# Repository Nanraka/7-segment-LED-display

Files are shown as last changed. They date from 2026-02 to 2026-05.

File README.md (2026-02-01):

# 7 segment LED display

hi

## What is it?
Seven-segment LEDs are commonly used to display numbers, but by combining multiple units, it is also possible to display images and arbitrary patterns.  
I built a system that controls a large number of seven-segment LEDs to display image data and custom-designed patterns as a large-scale display.

For more details, see: > https://elchika.com/article/256d17d7-ee96-4fee-8e8a-b19cc3068b17/

---
## HW
final

SPRESENSE was used for control.  
The seven-segment LEDs were controlled using a shift register with a dynamic (multiplexed) driving method.

The PCB design data is available here: > https://github.com/Nanraka/7-segment-LED-display/tree/main/schematics

Please refer to the table below for the connections to the display.  
To distribute the signal lines, I built a custom Arduino shield mounted on the SPRESENSE.

| Spresense Extension Board Pin | Display Pin | Description |
|---|---|---|
| D13 (SCK) | SCLK | SPI clock signal |
| D11 (MOSI) | SER, TSER | Data input (branched to SER and TSER) |
| D9 (CS) | CS | Chip select (Anode-side shift register) |
| D9 | RESET | Shift register output enable |
| D3 | TRCLK | Chip select (Cathode-side shift register) |
| D1 | OE | Shift register output enable |
| GND | GND | Ground (common reference) |

⚠️ Please connect a dedicated power supply to the VCC terminal of the seven-segment display.  
⚠️ Do not connect it to the SPRESENSE Vout 5V pin.

---
## SW

sw

The data sent from SPRESENSE to the display is prepared in advance on a PC.  
Python is used to convert the image data to be displayed into binary data.

The software data is available here: > https://github.com/Nanraka/7-segment-LED-display/tree/main/src

### 1. `make_base_csv.py`
This script generates mask data.

### 2. `img_2_serial.py`
This script performs the following processes:

- Resizes the input image  
- Converts the image to a binary (black-and-white) format, reads it column by column, converts it into serial data, and saves the result as `.txt` and `.csv` files  
- Rearranges the serial data into an order that can be visually recognized as an image by humans, and saves it as a `.csv` file

### 3. `make_data_for_7seg.py`
This script performs the following processes:

- Loads mask data that defines the positions of the seven-segment digits  
- Combines the image serial data with the mask data to generate data for displaying on the seven-segment LEDs

### 4. `7seg_spresense.ino`
- This program sends data to the seven-segment display in LSB-first order.
- The `.txt` file generated by `make_data_for_7seg.py` is stored on a microSD card and read by the SPRESENSE for use.

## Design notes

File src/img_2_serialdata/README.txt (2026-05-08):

SWを動かす順番

0. make_base_csv.py
    ・7セグのデジットの場所を示したマスクデータを生成します．

1. img_2_serial.py
    ・入力画像をリサイズします．
    ・画像を2値化して列方向に読み取りシリアル変換し，txtファイル，csvファイルに保存します．
    ・シリアルデータを人が画像として認識できる順番に変換してCSVファイルに保存します．
    ・出力用CSVファイル：serial_data_csv
    ・出力用TXTファイル：serial_data_txt
    ・確認用CSVファイル：confirm_serial_data.csv

2. make_data_for_7seg.py
    ・7セグのデジットの場所を示したマスクデータを読み込みます．
    ・画像のシリアルデータとマスクデータを組み合わせて，7セグに表示するためのデータを作成します．

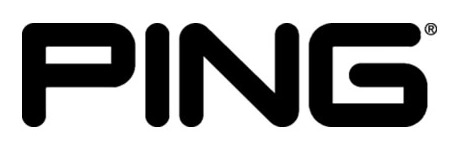
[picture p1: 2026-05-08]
src/img_2_serialdata/input.jpg

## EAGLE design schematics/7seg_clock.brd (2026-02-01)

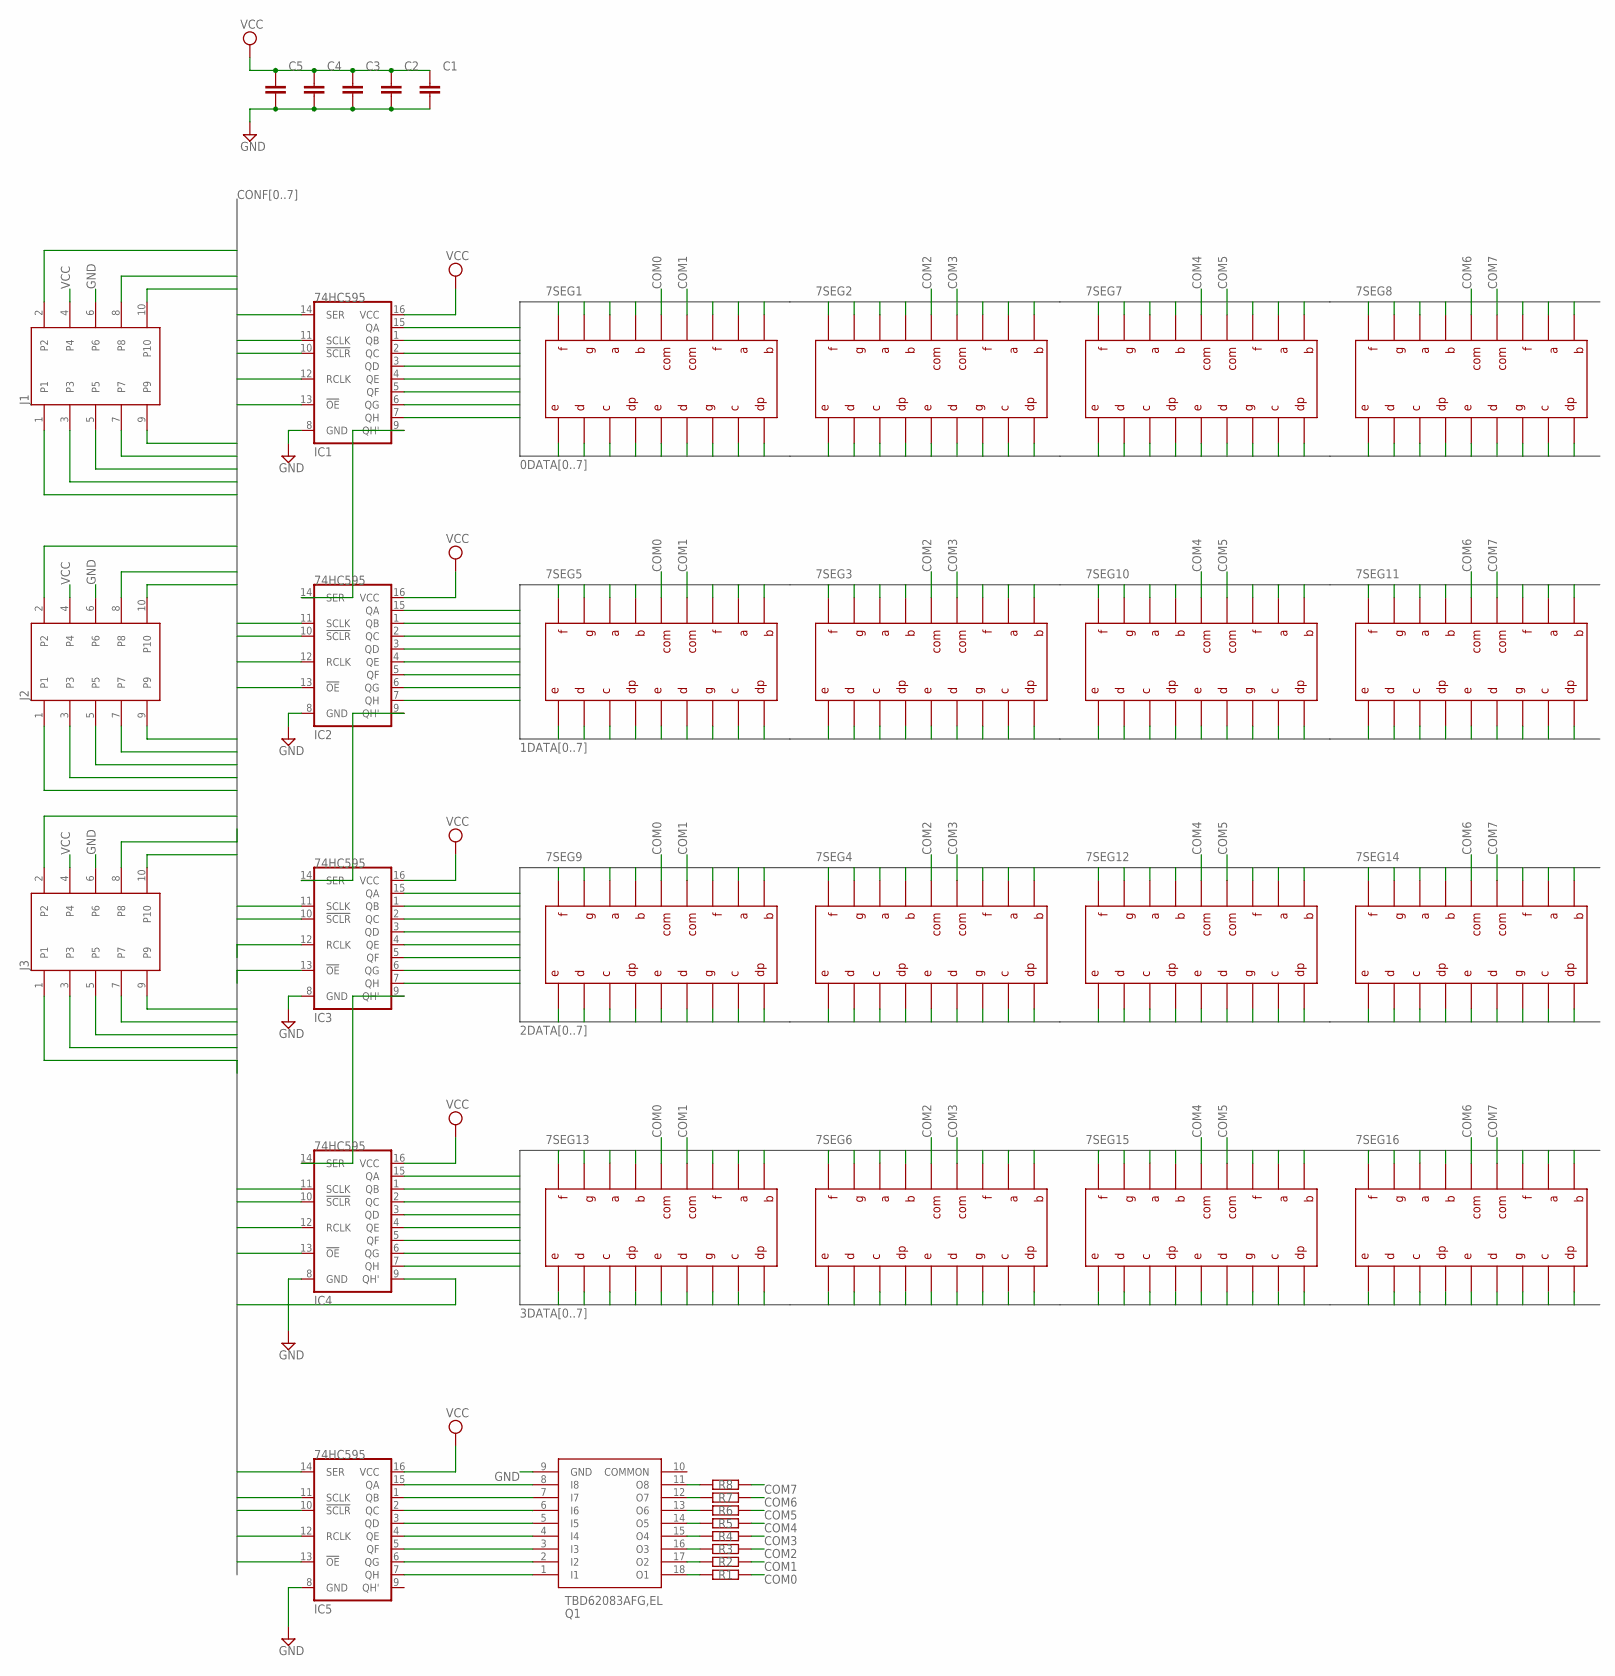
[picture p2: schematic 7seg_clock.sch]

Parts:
7SEG1, 7SEG2, 7SEG3, 7SEG4, 7SEG5, 7SEG6, 7SEG7, 7SEG8, 7SEG9, 7SEG10, 7SEG11, 7SEG12, 7SEG13, 7SEG14, 7SEG15, 7SEG16: SL-3264
C1, C2, C3, C4, C5: C_CHIP-0603(1608-METRIC); CAPC1608X85
IC1, IC2, IC3, IC4, IC5: 74HC595; SO16
J1, J2, J3: 1241050-5; TE_1241050-5
Q1: TBD62083AFG,EL; SOIC127P1030X245-18N
R1, R2, R3, R4, R5, R6, R7, R8: R_CHIP-0603(1608-METRIC); RESC1608X60

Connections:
0DATA0: 7SEG1.P$10, 7SEG1.P$15, 7SEG2.P$10, 7SEG2.P$15, 7SEG7.P$10, 7SEG7.P$15, 7SEG8.P$10, 7SEG8.P$15, IC1.15 (QA)
0DATA1: 7SEG1.P$12, 7SEG1.P$18, 7SEG2.P$12, 7SEG2.P$18, 7SEG7.P$12, 7SEG7.P$18, 7SEG8.P$12, 7SEG8.P$18, IC1.1 (QB)
0DATA2: 7SEG1.P$7, 7SEG1.P$17, 7SEG2.P$7, 7SEG2.P$17, 7SEG7.P$7, 7SEG7.P$17, 7SEG8.P$7, 7SEG8.P$17, IC1.2 (QC)
0DATA3: 7SEG1.P$11, 7SEG1.P$16, 7SEG2.P$11, 7SEG2.P$16, 7SEG7.P$11, 7SEG7.P$16, 7SEG8.P$11, 7SEG8.P$16, IC1.3 (QD)
0DATA4: 7SEG1.P$4, 7SEG1.P$9, 7SEG2.P$4, 7SEG2.P$9, 7SEG7.P$4, 7SEG7.P$9, 7SEG8.P$4, 7SEG8.P$9, IC1.4 (QE)
0DATA5: 7SEG1.P$3, 7SEG1.P$8, 7SEG2.P$3, 7SEG2.P$8, 7SEG7.P$3, 7SEG7.P$8, 7SEG8.P$3, 7SEG8.P$8, IC1.5 (QF)
0DATA6: 7SEG1.P$2, 7SEG1.P$6, 7SEG2.P$2, 7SEG2.P$6, 7SEG7.P$2, 7SEG7.P$6, 7SEG8.P$2, 7SEG8.P$6, IC1.6 (QG)
0DATA7: 7SEG1.P$1, 7SEG1.P$5, 7SEG2.P$1, 7SEG2.P$5, 7SEG7.P$1, 7SEG7.P$5, 7SEG8.P$1, 7SEG8.P$5, IC1.7 (QH)
1DATA0: 7SEG3.P$10, 7SEG3.P$15, 7SEG5.P$10, 7SEG5.P$15, 7SEG10.P$10, 7SEG10.P$15, 7SEG11.P$10, 7SEG11.P$15, IC2.15 (QA)
1DATA1: 7SEG3.P$12, 7SEG3.P$18, 7SEG5.P$12, 7SEG5.P$18, 7SEG10.P$12, 7SEG10.P$18, 7SEG11.P$12, 7SEG11.P$18, IC2.1 (QB)
1DATA2: 7SEG3.P$7, 7SEG3.P$17, 7SEG5.P$7, 7SEG5.P$17, 7SEG10.P$7, 7SEG10.P$17, 7SEG11.P$7, 7SEG11.P$17, IC2.2 (QC)
1DATA3: 7SEG3.P$11, 7SEG3.P$16, 7SEG5.P$11, 7SEG5.P$16, 7SEG10.P$11, 7SEG10.P$16, 7SEG11.P$11, 7SEG11.P$16, IC2.3 (QD)
1DATA4: 7SEG3.P$4, 7SEG3.P$9, 7SEG5.P$4, 7SEG5.P$9, 7SEG10.P$4, 7SEG10.P$9, 7SEG11.P$4, 7SEG11.P$9, IC2.4 (QE)
1DATA5: 7SEG3.P$3, 7SEG3.P$8, 7SEG5.P$3, 7SEG5.P$8, 7SEG10.P$3, 7SEG10.P$8, 7SEG11.P$3, 7SEG11.P$8, IC2.5 (QF)
1DATA6: 7SEG3.P$2, 7SEG3.P$6, 7SEG5.P$2, 7SEG5.P$6, 7SEG10.P$2, 7SEG10.P$6, 7SEG11.P$2, 7SEG11.P$6, IC2.6 (QG)
1DATA7: 7SEG3.P$1, 7SEG3.P$5, 7SEG5.P$1, 7SEG5.P$5, 7SEG10.P$1, 7SEG10.P$5, 7SEG11.P$1, 7SEG11.P$5, IC2.7 (QH)
2DATA0: 7SEG4.P$10, 7SEG4.P$15, 7SEG9.P$10, 7SEG9.P$15, 7SEG12.P$10, 7SEG12.P$15, 7SEG14.P$10, 7SEG14.P$15, IC3.15 (QA)
2DATA1: 7SEG4.P$12, 7SEG4.P$18, 7SEG9.P$12, 7SEG9.P$18, 7SEG12.P$12, 7SEG12.P$18, 7SEG14.P$12, 7SEG14.P$18, IC3.1 (QB)
2DATA2: 7SEG4.P$7, 7SEG4.P$17, 7SEG9.P$7, 7SEG9.P$17, 7SEG12.P$7, 7SEG12.P$17, 7SEG14.P$7, 7SEG14.P$17, IC3.2 (QC)
2DATA3: 7SEG4.P$11, 7SEG4.P$16, 7SEG9.P$11, 7SEG9.P$16, 7SEG12.P$11, 7SEG12.P$16, 7SEG14.P$11, 7SEG14.P$16, IC3.3 (QD)
2DATA4: 7SEG4.P$4, 7SEG4.P$9, 7SEG9.P$4, 7SEG9.P$9, 7SEG12.P$4, 7SEG12.P$9, 7SEG14.P$4, 7SEG14.P$9, IC3.4 (QE)
2DATA5: 7SEG4.P$3, 7SEG4.P$8, 7SEG9.P$3, 7SEG9.P$8, 7SEG12.P$3, 7SEG12.P$8, 7SEG14.P$3, 7SEG14.P$8, IC3.5 (QF)
2DATA6: 7SEG4.P$2, 7SEG4.P$6, 7SEG9.P$2, 7SEG9.P$6, 7SEG12.P$2, 7SEG12.P$6, 7SEG14.P$2, 7SEG14.P$6, IC3.6 (QG)
2DATA7: 7SEG4.P$1, 7SEG4.P$5, 7SEG9.P$1, 7SEG9.P$5, 7SEG12.P$1, 7SEG12.P$5, 7SEG14.P$1, 7SEG14.P$5, IC3.7 (QH)
3DATA0: 7SEG6.P$10, 7SEG6.P$15, 7SEG13.P$10, 7SEG13.P$15, 7SEG15.P$10, 7SEG15.P$15, 7SEG16.P$10, 7SEG16.P$15, IC4.15 (QA)
3DATA1: 7SEG6.P$12, 7SEG6.P$18, 7SEG13.P$12, 7SEG13.P$18, 7SEG15.P$12, 7SEG15.P$18, 7SEG16.P$12, 7SEG16.P$18, IC4.1 (QB)
3DATA2: 7SEG6.P$7, 7SEG6.P$17, 7SEG13.P$7, 7SEG13.P$17, 7SEG15.P$7, 7SEG15.P$17, 7SEG16.P$7, 7SEG16.P$17, IC4.2 (QC)
3DATA3: 7SEG6.P$11, 7SEG6.P$16, 7SEG13.P$11, 7SEG13.P$16, 7SEG15.P$11, 7SEG15.P$16, 7SEG16.P$11, 7SEG16.P$16, IC4.3 (QD)
3DATA4: 7SEG6.P$4, 7SEG6.P$9, 7SEG13.P$4, 7SEG13.P$9, 7SEG15.P$4, 7SEG15.P$9, 7SEG16.P$4, 7SEG16.P$9, IC4.4 (QE)
3DATA5: 7SEG6.P$3, 7SEG6.P$8, 7SEG13.P$3, 7SEG13.P$8, 7SEG15.P$3, 7SEG15.P$8, 7SEG16.P$3, 7SEG16.P$8, IC4.5 (QF)
3DATA6: 7SEG6.P$2, 7SEG6.P$6, 7SEG13.P$2, 7SEG13.P$6, 7SEG15.P$2, 7SEG15.P$6, 7SEG16.P$2, 7SEG16.P$6, IC4.6 (QG)
3DATA7: 7SEG6.P$1, 7SEG6.P$5, 7SEG13.P$1, 7SEG13.P$5, 7SEG15.P$1, 7SEG15.P$5, 7SEG16.P$1, 7SEG16.P$5, IC4.7 (QH)
COM0: 7SEG1.P$14, 7SEG5.P$14, 7SEG9.P$14, 7SEG13.P$14, R1.2
COM1: 7SEG1.P$13, 7SEG5.P$13, 7SEG9.P$13, 7SEG13.P$13, R2.2
COM2: 7SEG2.P$14, 7SEG3.P$14, 7SEG4.P$14, 7SEG6.P$14, R3.2
COM3: 7SEG2.P$13, 7SEG3.P$13, 7SEG4.P$13, 7SEG6.P$13, R4.2
COM4: 7SEG7.P$14, 7SEG10.P$14, 7SEG12.P$14, 7SEG15.P$14, R5.2
COM5: 7SEG7.P$13, 7SEG10.P$13, 7SEG12.P$13, 7SEG15.P$13, R6.2
COM6: 7SEG8.P$14, 7SEG11.P$14, 7SEG14.P$14, 7SEG16.P$14, R7.2
COM7: 7SEG8.P$13, 7SEG11.P$13, 7SEG14.P$13, 7SEG16.P$13, R8.2
CONF0: IC1.14 (SER), J1.1, J2.1, J3.1
CONF1: IC1.11 (SCLK), IC2.11 (SCLK), IC3.11 (SCLK), IC4.11 (SCLK), IC5.11 (SCLK), J1.7, J2.7, J3.7
CONF2: IC1.10 (!SCLR), IC2.10 (!SCLR), IC3.10 (!SCLR), IC4.10 (!SCLR), IC5.10 (!SCLR), J1.9, J2.9, J3.9
CONF3: IC1.12 (RCLK), IC2.12 (RCLK), IC3.12 (RCLK), IC4.12 (RCLK), J1.5, J2.5, J3.5
CONF4: IC1.13 (!OE), IC2.13 (!OE), IC3.13 (!OE), IC4.13 (!OE), IC5.13 (!OE), J1.3, J2.3, J3.3
CONF5: IC4.9 (QH'), J1.10, J2.10, J3.10
CONF6: IC5.14 (SER), J1.8, J2.8, J3.8
CONF7: IC5.12 (RCLK), J1.2, J2.2, J3.2
GND: C1.2, C2.2, C3.2, C4.2, C5.2, IC1.8 (GND), IC2.8 (GND), IC3.8 (GND), IC4.8 (GND), IC5.8 (GND), J1.6, J2.6, J3.6, Q1.9 (GND)
unnamed: IC1.9 (QH'), IC2.14 (SER)
unnamed: Q1.18 (O1), R1.1
unnamed: Q1.17 (O2), R2.1
unnamed: IC3.9 (QH'), IC4.14 (SER)
unnamed: Q1.16 (O3), R3.1
unnamed: IC5.7 (QH), Q1.1 (I1)
unnamed: IC5.6 (QG), Q1.2 (I2)
unnamed: IC5.5 (QF), Q1.3 (I3)
unnamed: IC5.4 (QE), Q1.4 (I4)
unnamed: Q1.15 (O4), R4.1
unnamed: Q1.14 (O5), R5.1
unnamed: IC5.3 (QD), Q1.5 (I5)
unnamed: IC5.2 (QC), Q1.6 (I6)
unnamed: IC5.1 (QB), Q1.7 (I7)
unnamed: IC5.15 (QA), Q1.8 (I8)
unnamed: Q1.13 (O6), R6.1
unnamed: Q1.12 (O7), R7.1
unnamed: Q1.11 (O8), R8.1
unnamed: IC2.9 (QH'), IC3.14 (SER)
VCC: C1.1, C2.1, C3.1, C4.1, C5.1, IC1.16 (VCC), IC2.16 (VCC), IC3.16 (VCC), IC4.16 (VCC), IC5.16 (VCC), J1.4, J2.4, J3.4

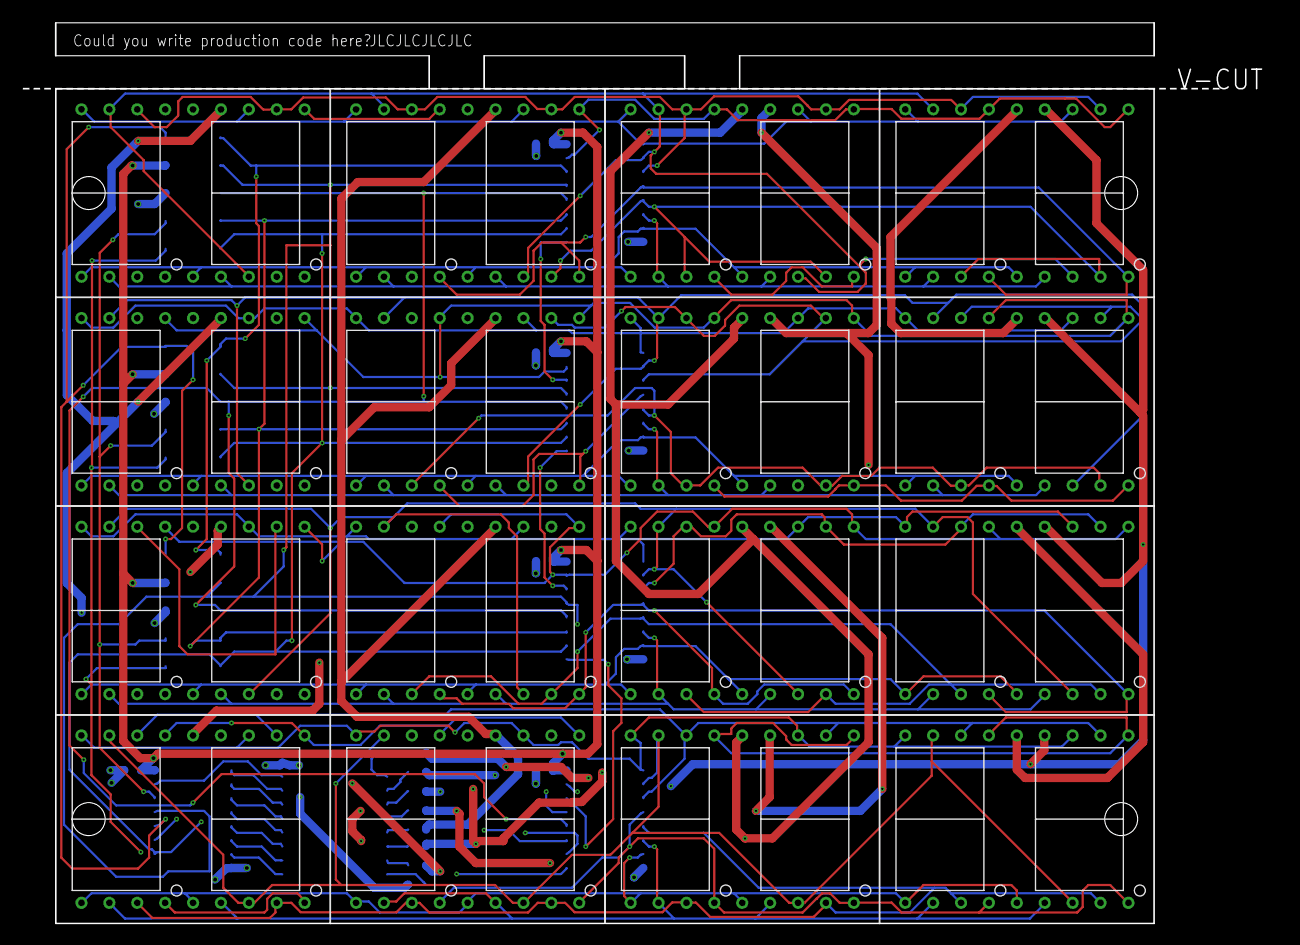
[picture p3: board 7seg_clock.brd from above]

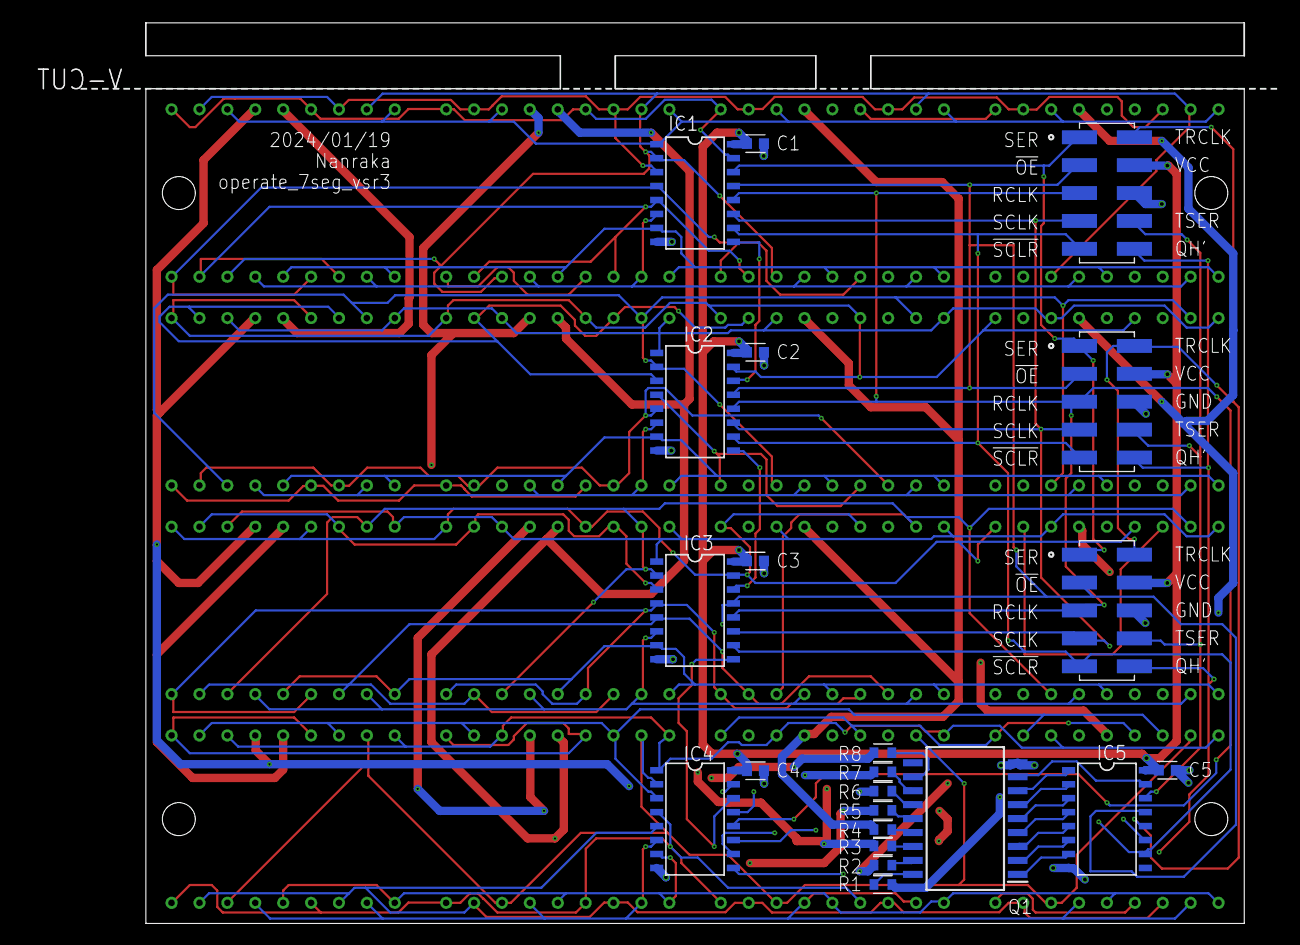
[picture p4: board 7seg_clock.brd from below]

Board: 4 copper layers, 109.0 x 82.0 mm, 38 parts (22 on the bottom side), 69 nets.

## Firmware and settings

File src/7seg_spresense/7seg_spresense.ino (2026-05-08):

#include <SDHCI.h>
#include <File.h>
#include <SPI.h>


#define DATA_SIZE 2048
#define BLOCK_SIZE   8 // 1列当たりの7セグメントLEDの数
#define GROUP_SIZE   64 // 1セットあたりの7セグメントLEDの数
#define GROUP_COUNT  5 // セット数
#define LOOP_COUNT   8


uint8_t rowData[DATA_SIZE];
uint8_t sendData[DATA_SIZE];

SDClass SD;

const int DATA_LATCH_PIN = 9;
const int TRAN_LATCH_PIN = 3;
const int OE_PIN = 1;

int tran_pos = 0;
int data_offset = 0;

uint8_t cathode_data = 0x01;



void sendToShiftRegister(int loop) {
  //列方向の遷移 下から上に上がっていく
  for (int i= 0; i < 32; i++) {
    SPI.transfer(sendData[i + data_offset]);
    //Serial.println(sendData[i], BIN);
  }
  data_offset += 32;
}



void packBitsToBytes() {

  for (int byteIndex = 0; byteIndex < (DATA_SIZE/8); byteIndex++) {

    uint8_t value = 0;

    // 1バイトにする
    for (int bit = 0; bit < 8; bit++) {
      value <<= 1;  // MSBから詰める
      value |= (rowData[byteIndex * 8 + bit] & 0x01);
    }
    sendData[byteIndex] = value;
  }
}



void setup() {
  Serial.begin(115200);
  while (!Serial);

  // SD初期化
  if (!SD.begin()) {
    Serial.println("SD init failed");
    return;
  }

  File file = SD.open("output.txt");
  if (!file) {
    Serial.println("File open failed");
    return;
  }

  int idx = 0;
  while (file.available() && idx < DATA_SIZE) {
    char c = file.read();
    if (c == '0' || c == '1') {
      rowData[idx++] = c - '0';
    }
  }
  file.close();

  Serial.print("Loaded: ");
  Serial.println(idx);

  packBitsToBytes();

  for (int i= 0; i < 128; i++) {
    Serial.println(sendData[i], BIN);
  }

  // SPI初期化
  SPI.begin();
  SPI.beginTransaction(SPISettings(8000000, LSBFIRST, SPI_MODE0));

  pinMode(DATA_LATCH_PIN, OUTPUT);
  pinMode(TRAN_LATCH_PIN, OUTPUT);
  pinMode(OE_PIN, OUTPUT);

  digitalWrite(DATA_LATCH_PIN, HIGH);
  digitalWrite(TRAN_LATCH_PIN, HIGH);
  digitalWrite(OE_PIN, HIGH);
}

void loop() {
  digitalWrite(OE_PIN, HIGH);

  for (int loopCount = 0; loopCount < LOOP_COUNT; loopCount++) {

    digitalWrite(DATA_LATCH_PIN, LOW);
    digitalWrite(TRAN_LATCH_PIN, HIGH);
    sendToShiftRegister(loopCount);

    digitalWrite(DATA_LATCH_PIN, HIGH);
    digitalWrite(TRAN_LATCH_PIN, LOW);
    //uint8_t data = (0x80 >> tran_pos);
    SPI.transfer(cathode_data);

    digitalWrite(DATA_LATCH_PIN, HIGH);
    digitalWrite(TRAN_LATCH_PIN, HIGH);
    digitalWrite(OE_PIN, LOW);

    tran_pos += 1;
    cathode_data = cathode_data << 1;

    //Serial.println(data,BIN);

    if (tran_pos >= 8){
      tran_pos = 0;
      cathode_data = 0x01;
      data_offset = 0;
    }

    delay(2);  // 出力更新周期
  }

}

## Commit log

2026-02-01 Add readme for 7 segment LED display
    Added detailed information about the 7 segment LED display project, including hardware and software components.
2026-02-01 Removal of unnecessary files
    [7seg_clock.brd, 7seg_clock.sch, 7seg_clock_ver2.brd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]
2026-05-06 edit sch file name
    [7seg_clock.brd, 7seg_clock.sch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]
2026-05-08 Modified the orientation to make the screen easier to see.
    [confirm_serial_data.csv, mask_data.csv, mask_data.xlsx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]
